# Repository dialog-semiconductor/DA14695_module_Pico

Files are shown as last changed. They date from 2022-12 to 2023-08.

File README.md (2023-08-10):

# Renesas DA14695MOD Pico Board

The Renesas DA14695MOD Pico board is a versatile 2-layer development board designed with compatibility and functionality in mind. Designed to be compatible with the Pico pinout, this board offers a range of features including Bluetooth Low Energy (BLE) capabilities, USB connectivity, a battery connector equipped with an on-chip charger, and 4 MB of onboard FLASH storage.

## Features

- **BLE 5.2 Connectivity**: Leverage the power of Bluetooth Low Energy 5.2 with the integrated SmartBond DA14695 SoC.
- **USB Connectivity**: Easily connect and communicate with the board using the USB interface.
- **Battery Charging**: The onboard battery connector, coupled with the on-chip charger, allows for convenient battery management.

## DA14695 Module 

The board is based on the SmartBond DA14695 Bluetooth low energy 5.2 system-on-chip (SoC), making it a comprehensive solution for various applications. The DA14695 Module encompasses all the hardware features and capabilities of the DA14695 SoC, with integrated passives, an antenna, a 32Mbit QSPI FLASH, and user-friendly software support. The module's design focuses on broad market use, offering certifications across regions. This approach translates to reduced development costs, minimized risks, and faster time-to-market.

For detailed technical specifications of the DA14695 Module, refer to the [Renesas website](https://www.renesas.com/us/en/products/wireless-connectivity/bluetooth-low-energy/da14695mod-smartbond-bluetooth-le-52-high-integration-including-usb-charger-module).

## Repository Contents

This GitHub repository houses all the design files for the DA14695MOD Pico board. These files are compatible with KiCAD 6. The full schematic is included as pdf PDF [here](Assets/Pico%20schematic%20final.pdf).

## Board Pinout

To help you get started quickly, here's a visual representation of the board's pinout:

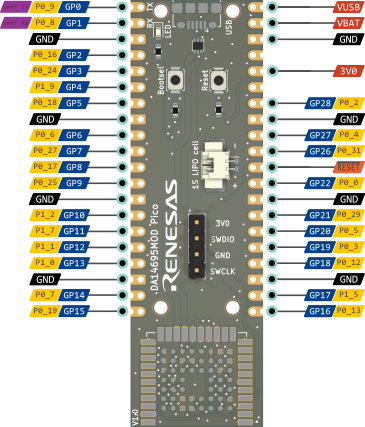
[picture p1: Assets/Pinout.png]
DA14695MOD Pico board pinout


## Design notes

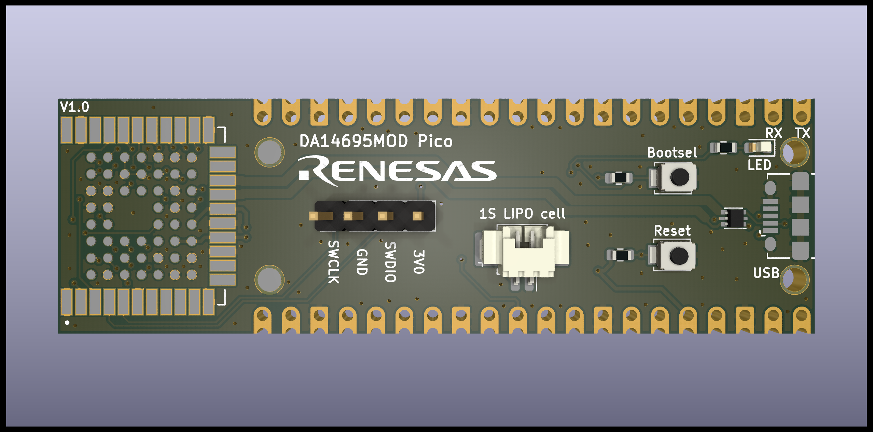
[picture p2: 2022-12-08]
Assets/690 module pico front.png

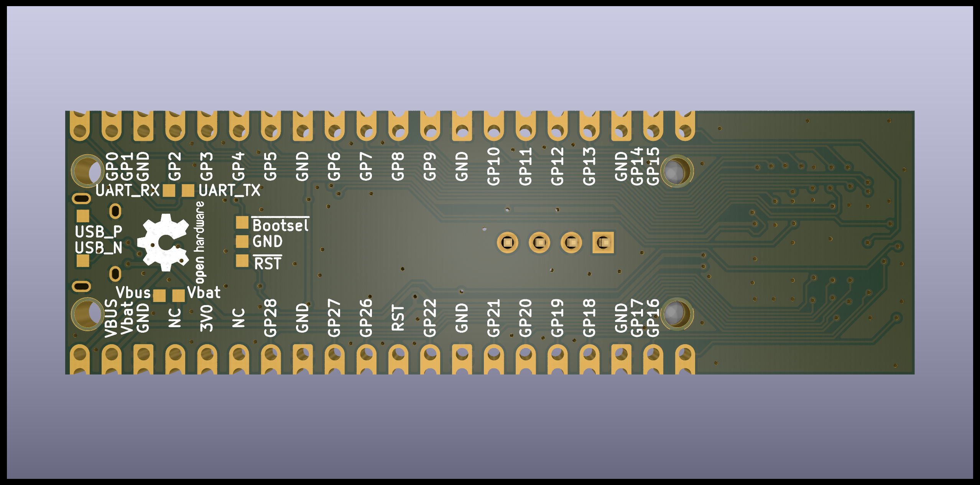
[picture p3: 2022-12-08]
Assets/690 module pico back.png

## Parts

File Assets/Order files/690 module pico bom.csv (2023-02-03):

Component | Description | Part | References | Value | Footprint | Quantity Per PCB | Datasheet | LCSC partnumber | MANUFACTURER | SNAPEDA_PN | STANDARD
1 | Single-cell battery | Battery_Cell | BT1 | Battery_Cell | Molex_PicoBlade_53261-0271_1x02-1MP_P1.25mm_Horizontal | 1 | ~ | C189700
2 | Light emitting diode | LED | D1 | usr_led | LED_0603_1608Metric | 1 | ~ | C72043
3 | Generic connector, single row, 01x04, script generated (kicad-library-utils/schlib/autogen/connector/) | Conn_01x04_Male | J1 | Conn_01x04_Male | PinHeader_1x04_P2.54mm_Vertical | 1 | ~
4 | USB Micro Type B connector | USB_B_Micro | J2 | USB_B_Micro | USB_Micro-B_Amphenol_10118194_Horizontal | 1 | ~ | C404969
5 | Resistor | R | R1 | 470 | R_0603_1608Metric | 1 | ~ | C23179
6 | Resistor | R | R2 R3 | 10k | R_0603_1608Metric | 2 | ~ | C25804
7 | Push button switch, generic, two pins | SW_Push | SW1 | Bootsel | SW_SPST_B3U-1000P | 1 | ~ | C231329
8 | Push button switch, generic, two pins | SW_Push | SW2 | Reset | SW_SPST_B3U-1000P | 1 | ~ | C231329
9 |  | DA14695_000HQ2 | U2 | DA14695_000HQ2 | MODULE_DA14695_000HQ2 | 1 |  |  | Renesas | DA14695_HQ2_Module | Manufacturer Recommendations
10 | Very low capacitance ESD protection diode, 2 data-line, SOT-666 | USBLC6-2P6 | U1 | USBLC6-2P6 | SOT-666 | 1 | https://www.st.com/resource/en/datasheet/usblc6-2.pdf | C2827693

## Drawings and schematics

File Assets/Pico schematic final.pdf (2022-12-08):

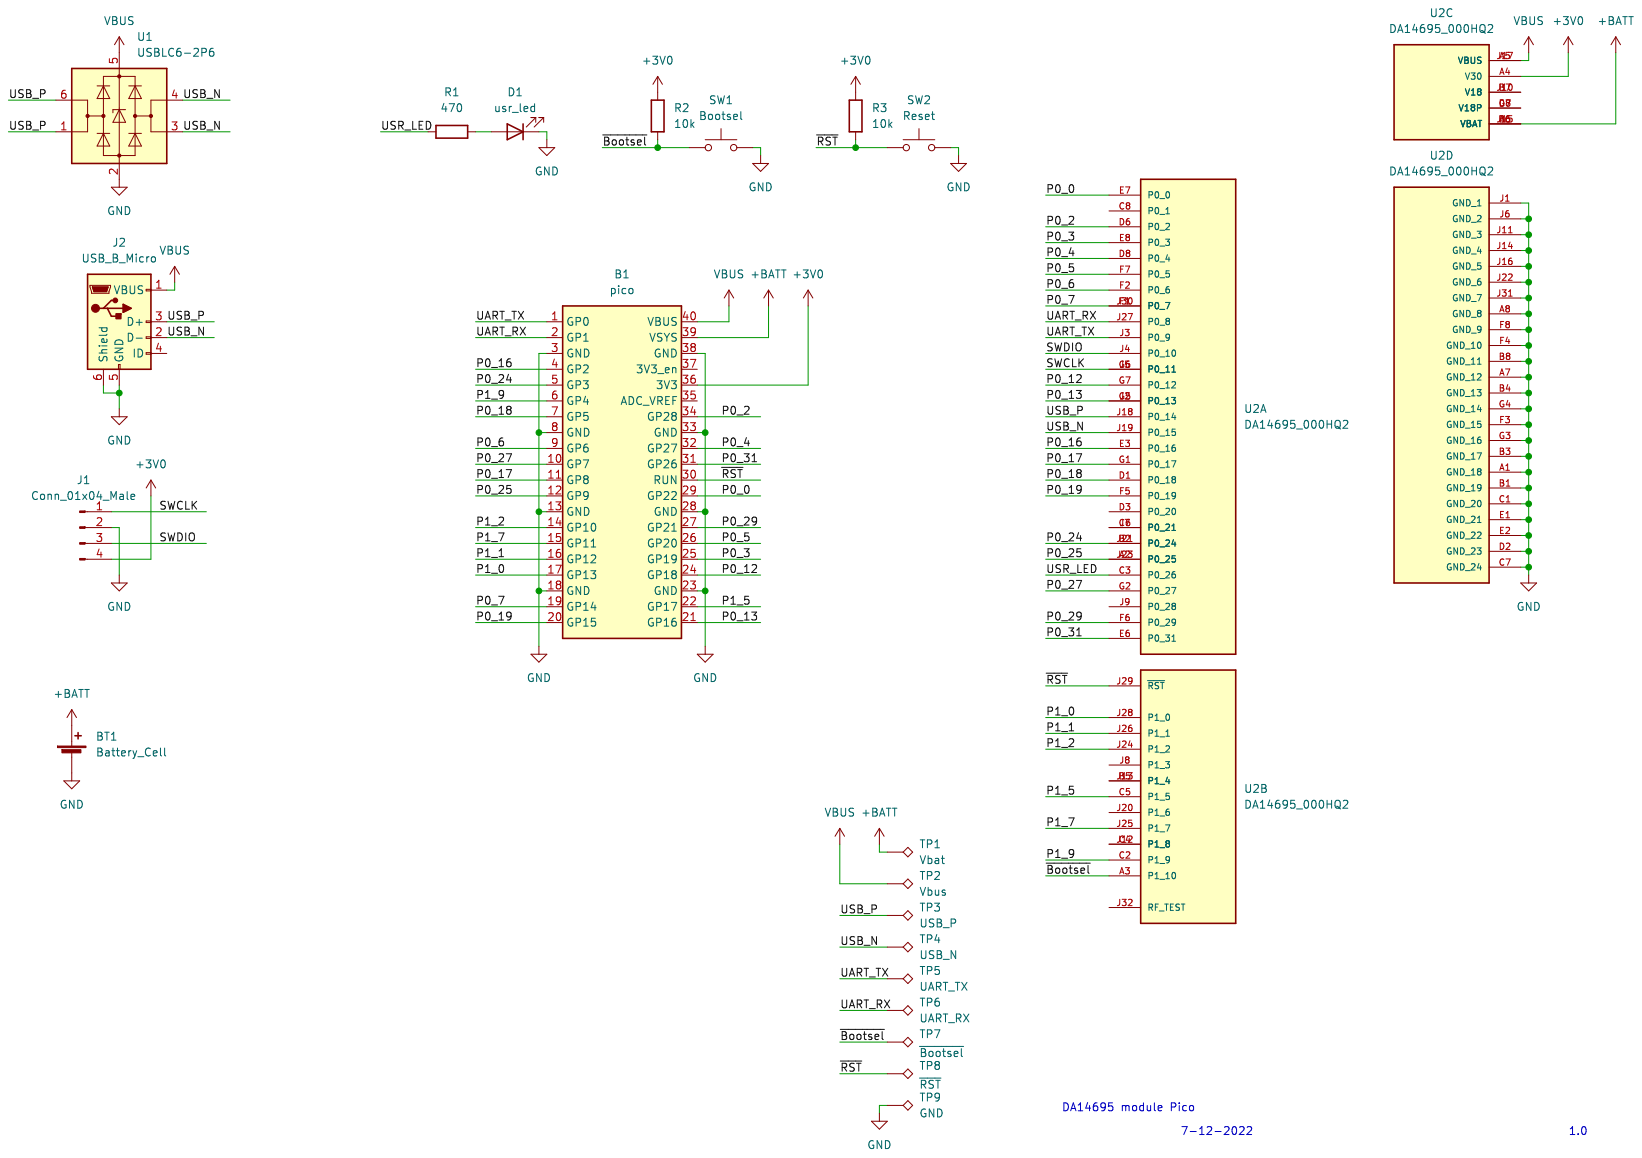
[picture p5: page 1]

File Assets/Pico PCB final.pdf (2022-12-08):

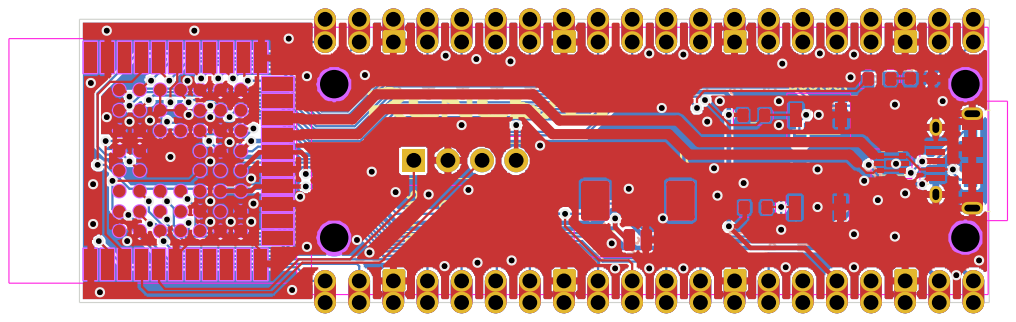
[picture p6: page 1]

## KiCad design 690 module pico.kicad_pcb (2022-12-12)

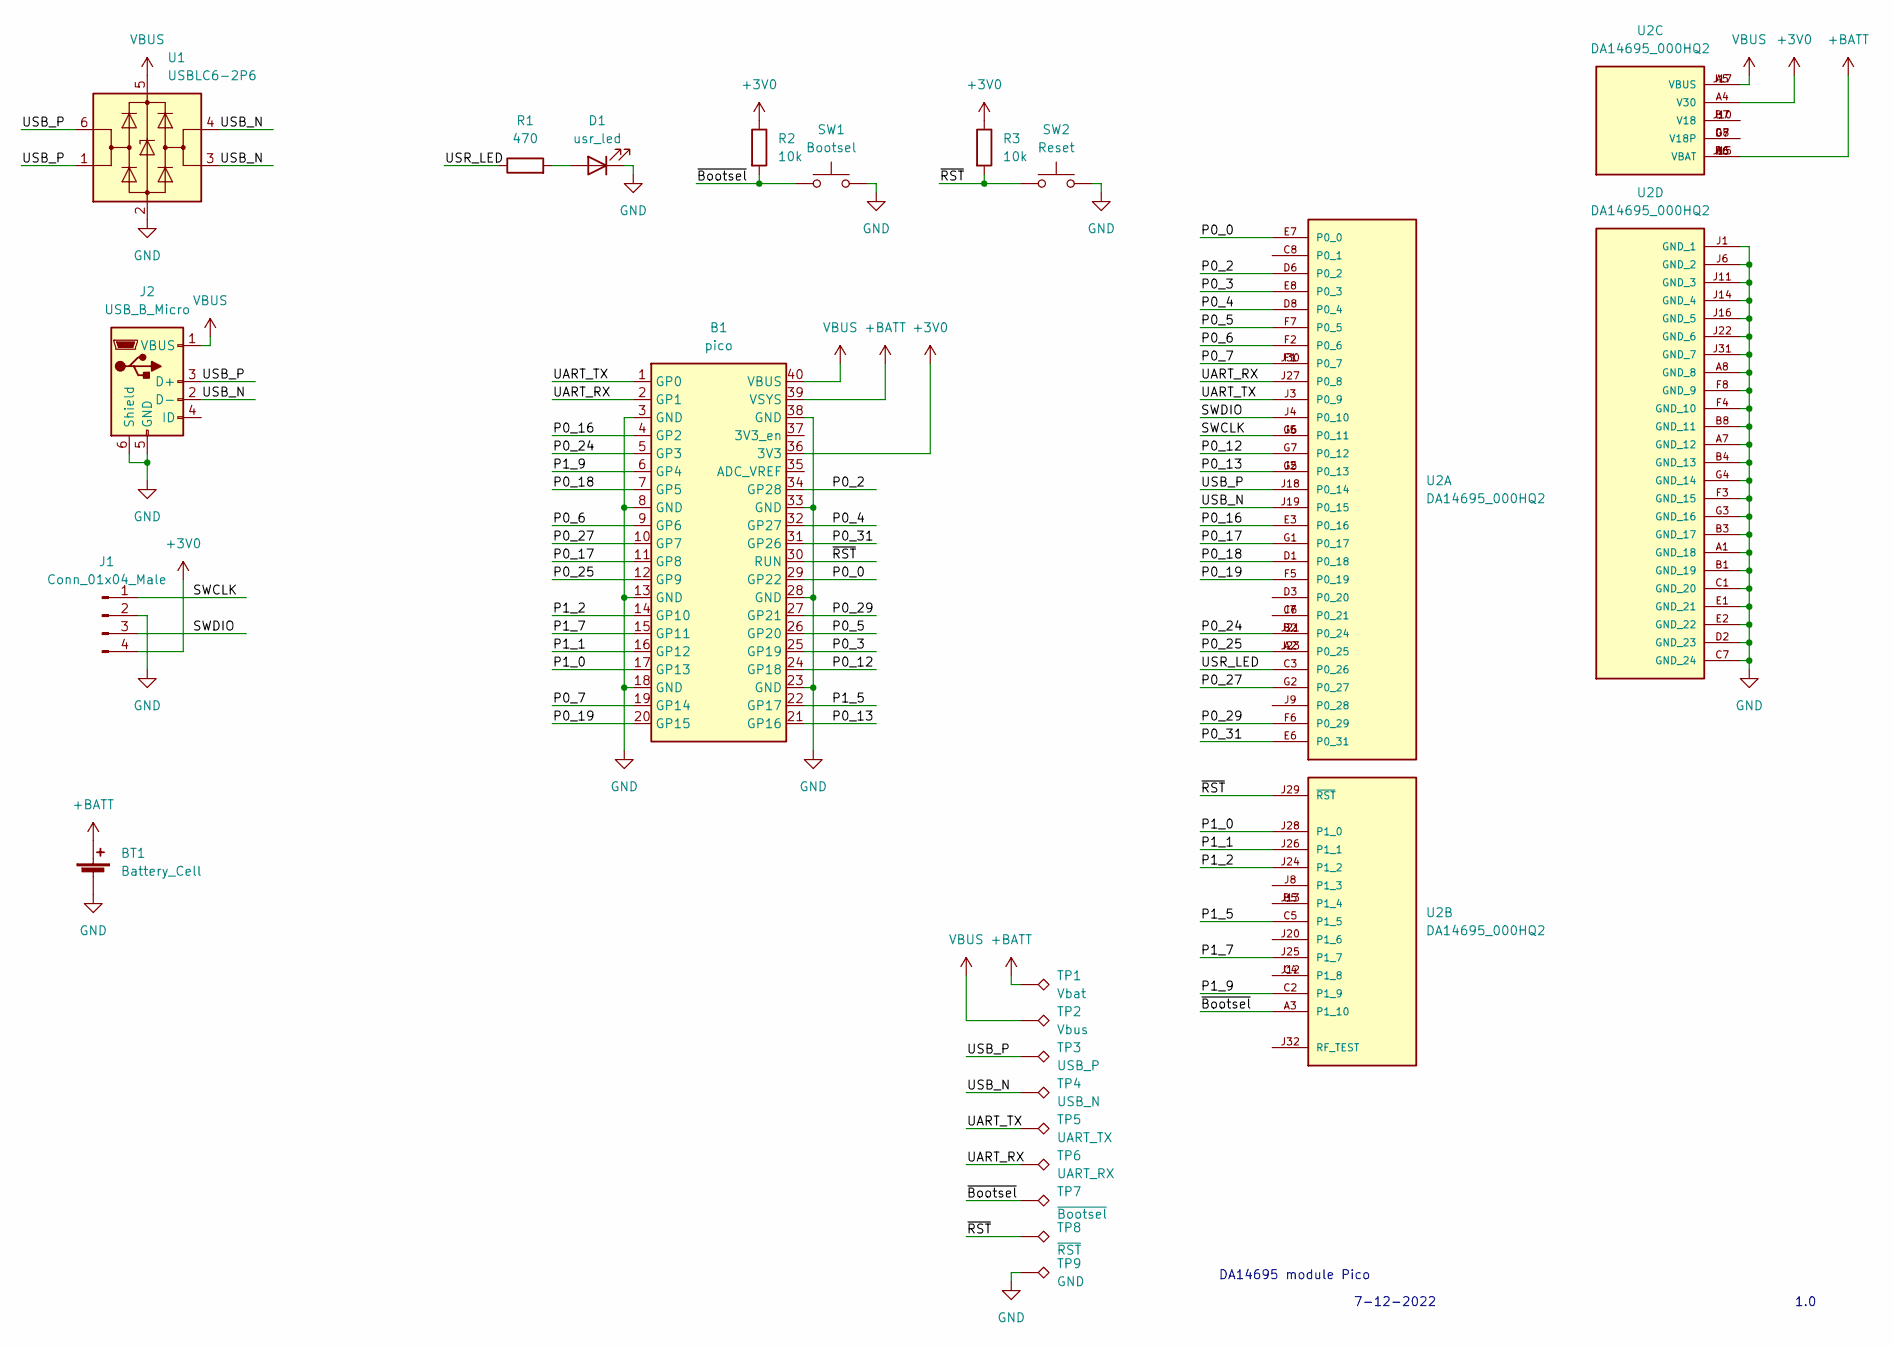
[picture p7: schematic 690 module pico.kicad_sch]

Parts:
B1: pico; Pico
BT1: Battery_Cell; Molex_PicoBlade_53261-0271_1x02-1MP_P1.25mm_Horizontal; LCSC partnumber C189700
D1: usr_led; LED_0603_1608Metric; LCSC partnumber C72043
J1: Conn_01x04_Male; PinHeader_1x04_P2.54mm_Vertical
J2: USB_B_Micro; USB_Micro-B_Amphenol_10118194_Horizontal; LCSC partnumber C381144
R1: 470; R_0603_1608Metric; LCSC partnumber C23179
R2, R3: 10k; R_0603_1608Metric; LCSC partnumber C25804
SW1: Bootsel; SW_SPST_B3U-1000P; LCSC partnumber C231329
SW2: Reset; SW_SPST_B3U-1000P; LCSC partnumber C231329
TP1: Vbat; TestPoint_Pad_1.0x1.0mm_custom
TP2: Vbus; TestPoint_Pad_1.0x1.0mm_custom
TP3: USB_P; TestPoint_Pad_1.0x1.0mm_custom
TP4: USB_N; TestPoint_Pad_1.0x1.0mm_custom
TP5: UART_TX; TestPoint_Pad_1.0x1.0mm_custom
TP6: UART_RX; TestPoint_Pad_1.0x1.0mm_custom
TP7: ~{Bootsel}; TestPoint_Pad_1.0x1.0mm_custom
TP8: ~{RST}; TestPoint_Pad_1.0x1.0mm_custom
TP9: GND; TestPoint_Pad_1.0x1.0mm_custom
U1: USBLC6-2P6; SOT-666; LCSC partnumber C2827693
U2: DA14695_000HQ2; MODULE_DA14695_000HQ2

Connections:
+3V0: B1.36 (3V3), J1.4, R2.1, R3.1, U2.A4 (V30)
+BATT: B1.39 (VSYS), BT1.2 (+), TP1.1, U2.A6 (VBAT), U2.B6 (VBAT), U2.J15 (VBAT)
/P0_0: B1.29 (GP22), U2.E7 (P0_0)
/P0_2: B1.34 (GP28), U2.D6 (P0_2)
/P0_3: B1.25 (GP19), U2.E8 (P0_3)
/P0_4: B1.32 (GP27), U2.D8 (P0_4)
/P0_5: B1.26 (GP20), U2.F7 (P0_5)
/P0_6: B1.9 (GP6), U2.F2 (P0_6)
/P0_7: B1.19 (GP14), U2.F1 (P0_7), U2.J30 (P0_7)
/P0_12: B1.24 (GP18), U2.G7 (P0_12)
/P0_13: B1.21 (GP16), U2.G5 (P0_13), U2.J2 (P0_13)
/P0_16: B1.4 (GP2), U2.E3 (P0_16)
/P0_17: B1.11 (GP8), U2.G1 (P0_17)
/P0_18: B1.7 (GP5), U2.D1 (P0_18)
/P0_19: B1.20 (GP15), U2.F5 (P0_19)
/P0_24: B1.5 (GP3), U2.B2 (P0_24), U2.J21 (P0_24)
/P0_25: B1.12 (GP9), U2.A2 (P0_25), U2.J23 (P0_25)
/P0_27: B1.10 (GP7), U2.G2 (P0_27)
/P0_29: B1.27 (GP21), U2.F6 (P0_29)
/P0_31: B1.31 (GP26), U2.E6 (P0_31)
/P1_0: B1.17 (GP13), U2.J28 (P1_0)
/P1_1: B1.16 (GP12), U2.J26 (P1_1)
/P1_2: B1.14 (GP10), U2.J24 (P1_2)
/P1_5: B1.22 (GP17), U2.C5 (P1_5)
/P1_7: B1.15 (GP11), U2.J25 (P1_7)
/P1_9: B1.6 (GP4), U2.C2 (P1_9)
/SWCLK: J1.1, U2.G6 (P0_11), U2.J5 (P0_11)
/SWDIO: J1.3, U2.J4 (P0_10)
/UART_RX: B1.2 (GP1), TP6.1, U2.J27 (P0_8)
/UART_TX: B1.1 (GP0), TP5.1, U2.J3 (P0_9)
/USB_N: J2.2 (D-), TP4.1, U1.3 (I/O2), U1.4 (I/O2), U2.J19 (P0_15)
/USB_P: J2.3 (D+), TP3.1, U1.1 (I/O1), U1.6 (I/O1), U2.J18 (P0_14)
/USR_LED: R1.1, U2.C3 (P0_26)
/~Bootsel: R2.2, SW1.1, TP7.1, U2.A3 (P1_10)
/~RST: B1.30 (RUN), R3.2, SW2.1, TP8.1, U2.J29 (~RST)
GND: B1.3 (GND), B1.8 (GND), B1.13 (GND), B1.18 (GND), B1.23 (GND), B1.28 (GND), B1.33 (GND), B1.38 (GND), BT1.1 (-), D1.1 (K), J1.2, J2.5 (GND), J2.6 (Shield), SW1.2, SW2.2, TP9.1, U1.2 (GND), U2.A1 (GND_18), U2.A7 (GND_12), U2.A8 (GND_8), U2.B1 (GND_19), U2.B3 (GND_17), U2.B4 (GND_13), U2.B8 (GND_11), U2.C1 (GND_20), U2.C7 (GND_24), U2.D2 (GND_23), U2.E1 (GND_21), U2.E2 (GND_22), U2.F3 (GND_15), U2.F4 (GND_10), U2.F8 (GND_9), U2.G3 (GND_16), U2.G4 (GND_14), U2.J1 (GND_1), U2.J6 (GND_2), U2.J11 (GND_3), U2.J14 (GND_4), U2.J16 (GND_5), U2.J22 (GND_6), U2.J31 (GND_7)
unnamed: D1.2 (A), R1.2
unnamed: U2.B5 (P1_4), U2.J13 (P1_4)
unnamed: U2.B7 (V18), U2.J10 (V18)
unnamed: U2.C4 (P1_8), U2.J12 (P1_8)
unnamed: U2.C6 (P0_21), U2.J7 (P0_21)
unnamed: U2.D7 (V18P), U2.G8 (V18P)
VBUS: B1.40 (VBUS), J2.1 (VBUS), TP2.1, U1.5 (VBUS), U2.A5 (VBUS), U2.J17 (VBUS)

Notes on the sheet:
1.0
DA14695 module Pico
7-12-2022

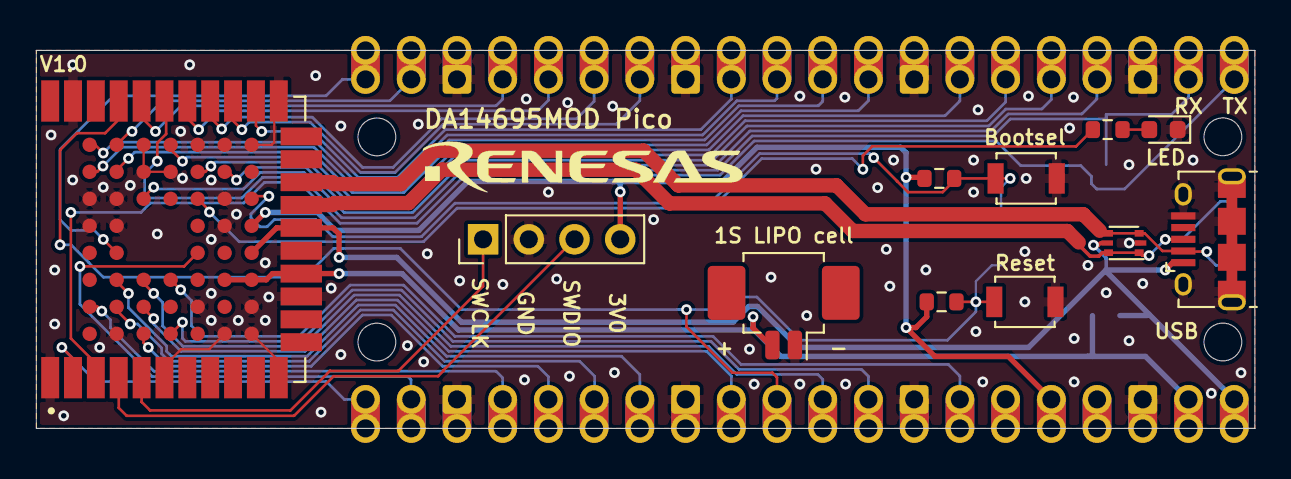
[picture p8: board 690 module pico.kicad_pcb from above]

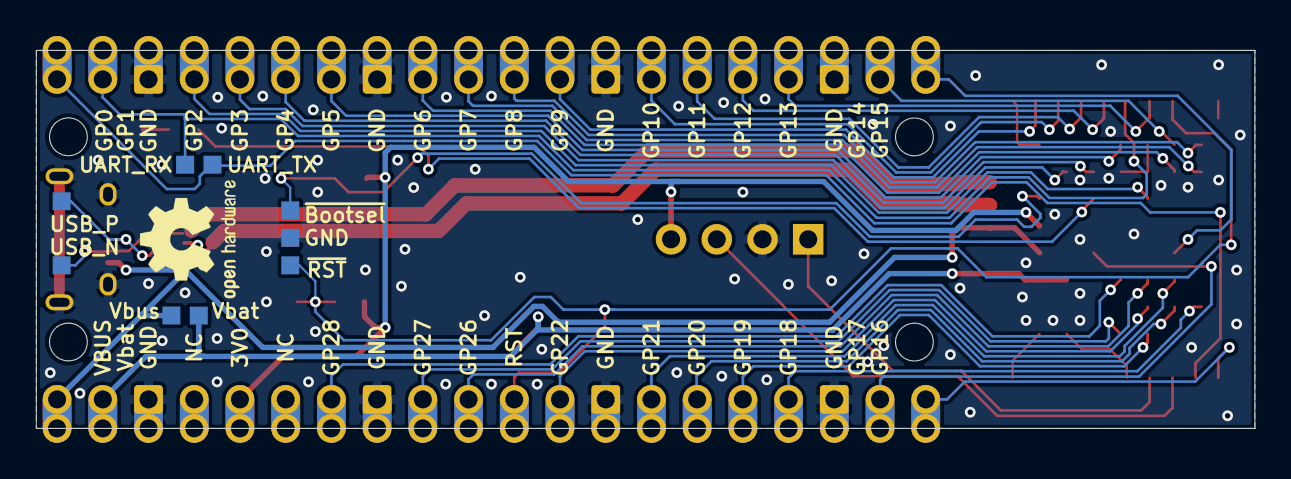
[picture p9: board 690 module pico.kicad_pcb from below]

Board: 2 copper layers, 67.7 x 21.0 mm, 21 parts (9 on the bottom side), 43 nets.

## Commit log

2022-12-08 Ordered version 1
    [690 module pico.kicad_pcb, 690 module pico.kicad_sch]
2022-12-12 Added pinout picture
    [690 module pico.kicad_pcb]
2023-01-20 Add order files and replace USB connector
    [690 module pico bom.csv, 690 module pico top placement.csv, 690 module pico.kicad_sch]
